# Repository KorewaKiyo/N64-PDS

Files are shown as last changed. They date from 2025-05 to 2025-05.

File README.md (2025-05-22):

# N64-PDS
## A USB-PD PSU for the Nintendo 64
This project aims to replace the bulky AC power supply of the n64 with a small, flush USB-PD supply.

The board is currently in V1 prototyping stage,
It will currently only support 15v supplies, though 5,9,15 are intended to be supported.
### Board view
animation

rendered with [kicad-render](https://github.com/linalinn/kicad-render)

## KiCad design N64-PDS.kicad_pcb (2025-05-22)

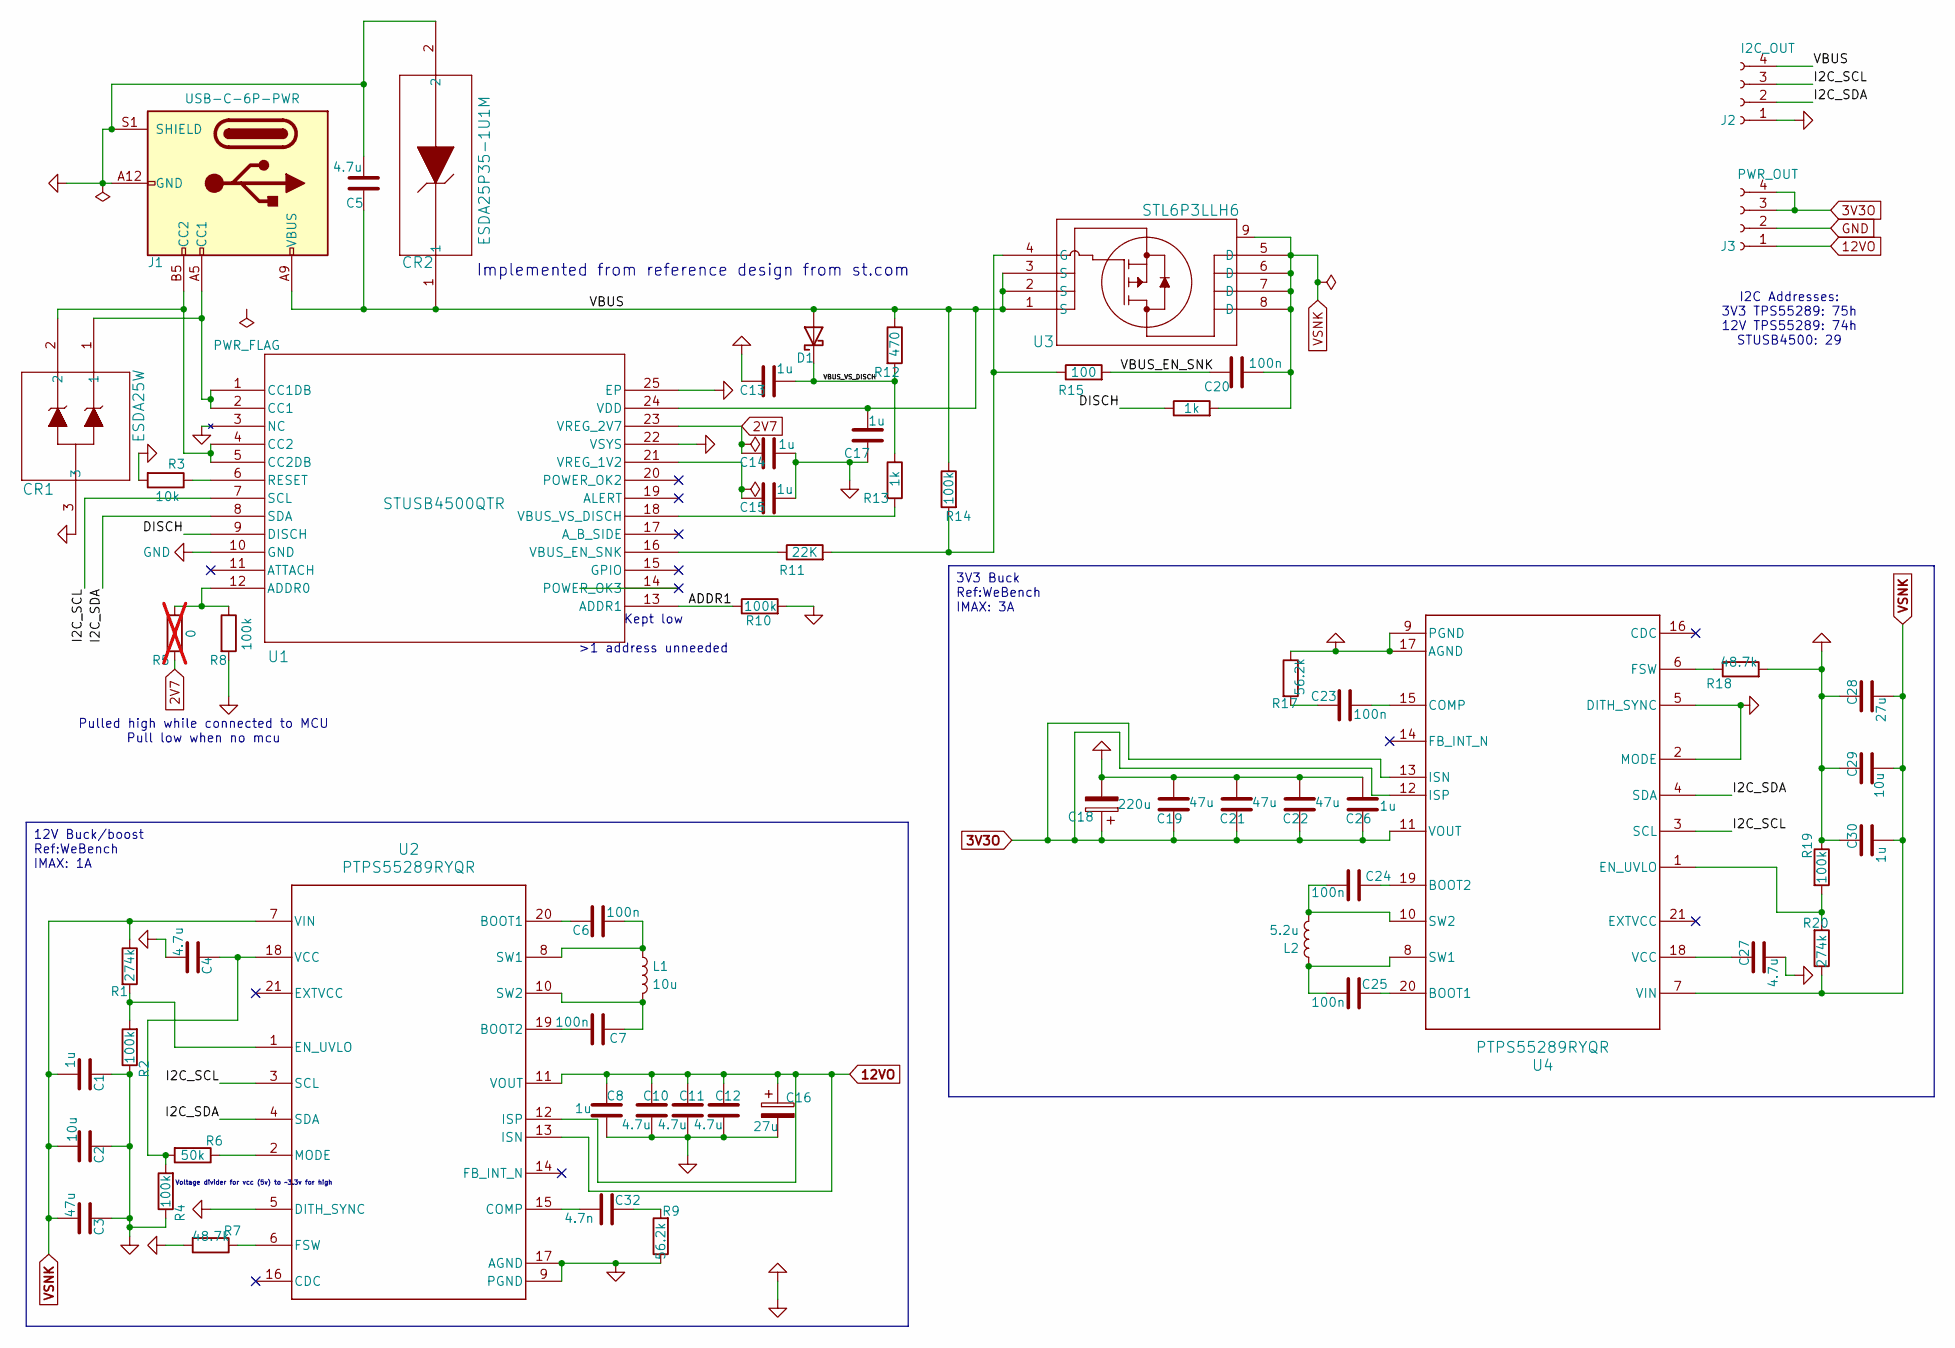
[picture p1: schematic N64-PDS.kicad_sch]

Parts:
C1, C13, C14, C15, C17, C30: 1u; C_0402_1005Metric_Pad0.74x0.62mm_HandSolder
C2, C29: 10u; C_1210_3225Metric_Pad1.33x2.70mm_HandSolder
C3: 47u; C_Elec_6.3x5.8
C4, C27: 4.7u; C_0603_1608Metric_Pad1.08x0.95mm_HandSolder
C5, C10, C11, C12: 4.7u; C_0805_2012Metric_Pad1.18x1.45mm_HandSolder
C6, C7, C24, C25: 100n; C_0603_1608Metric_Pad1.08x0.95mm_HandSolder
C8, C26: 1u; C_0603_1608Metric_Pad1.08x0.95mm_HandSolder
C16: 27u; CP_Elec_5x5.9
C18: 220u; CP_Elec_6.3x5.9
C19, C21, C22: 47u; C_0805_2012Metric_Pad1.18x1.45mm_HandSolder
C20: 100n; C_0504_1310Metric_Pad0.83x1.28mm_HandSolder
C23: 100n; C_0402_1005Metric_Pad0.74x0.62mm_HandSolder
C28: 27u; C_Elec_5x5.8
C32: 4.7n; C_0402_1005Metric_Pad0.74x0.62mm_HandSolder
CR1: ESDA25W; SOT323-3L_STM-M
CR2: ESDA25P35-1U1M; QFN1610_STM-M
D1: D_0402_1005Metric_Pad0.77x0.64mm_HandSolder
J1: USB-C-6P-PWR; USB_C_Receptacle_GCT_USB4125-xx-x-0190_6P_TopMnt_Horizontal
J2: I2C_OUT; Molex_PicoBlade_53047-0410_1x04_P1.25mm_Vertical
J3: PWR_OUT; JST_NV_B04P-NV_1x04_P5.00mm_Vertical
L1: 10u; DR1040-5R2-R
L2: 5.2u; L_Coilcraft_XAL6060-XXX
R1, R20: 274k; R_0402_1005Metric_Pad0.72x0.64mm_HandSolder
R2, R4, R8, R10, R14, R19: 100k; R_0402_1005Metric_Pad0.72x0.64mm_HandSolder
R3: 10k; R_0402_1005Metric_Pad0.72x0.64mm_HandSolder
R5: 0; R_0402_1005Metric_Pad0.72x0.64mm_HandSolder; not fitted
R6: 50k; R_0402_1005Metric_Pad0.72x0.64mm_HandSolder
R7, R18: 48.7k; R_0402_1005Metric_Pad0.72x0.64mm_HandSolder
R9, R17: 56.2k; R_0402_1005Metric_Pad0.72x0.64mm_HandSolder
R11: 22K; R_0402_1005Metric_Pad0.72x0.64mm_HandSolder
R12: 470; R_0402_1005Metric_Pad0.72x0.64mm_HandSolder
R13, R16: 1k; R_0402_1005Metric_Pad0.72x0.64mm_HandSolder
R15: 100; R_0402_1005Metric_Pad0.72x0.64mm_HandSolder
U1: STUSB4500QTR; QFN24EP_4X4_STM-M
U2, U4: PTPS55289RYQR; RYQ0021A-MFG
U3: STL6P3LLH6; POWERFLAT_3P3X3P3_STM

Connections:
2V7: C14.1, R5.2, U1.23 (VREG_2V7)
3V3O: C18.1, C19.2, C21.2, C22.2, C26.2, J3.3, J3.4, U4.11 (VOUT), U4.12 (ISP), U4.13 (ISN)
12VO: C8.2, C10.2, C11.2, C12.2, C16.1, J3.1, U2.11 (VOUT), U2.12 (ISP), U2.13 (ISN)
/ADDR1: R10.1, U1.13 (ADDR1)
/DISCH: R16.1, U1.9 (DISCH)
/I2C_SCL: J2.3, U1.7 (SCL), U2.3 (SCL), U4.3 (SCL)
/I2C_SDA: J2.2, U1.8 (SDA), U2.4 (SDA), U4.4 (SDA)
/VBUS: C5.1, C17.1, CR2.1, D1.2 (A), J1.A9 (VBUS), J1.B9 (VBUS), J2.4, R12.1, R14.1, U1.24 (VDD), U3.1 (S), U3.2 (S), U3.3 (S)
/VBUS_EN_SNK: C20.1, R15.2
/VBUS_VS_DISCH: C13.2, D1.1 (K), R12.2, R13.1
GND: C1.2, C2.2, C3.2, C4.1, C5.2, C8.1, C10.1, C11.1, C12.1, C13.1, C14.2, C15.2, C16.2, C17.2, C18.2, C19.1, C21.1, C22.1, C26.1, C27.1, C28.2, C29.2, C30.2, CR1.3, CR2.2, J1.A12 (GND), J1.B12 (GND), J1.S1 (SHIELD), J2.1, J3.2, R2.1, R3.2, R4.1, R7.2, R8.2, R9.1, R10.2, R17.1, R18.2, R19.1, U1.3 (NC), U1.10 (GND), U1.22 (VSYS), U1.25 (EP), U2.5 (DITH_SYNC), U2.9 (PGND), U2.17 (AGND), U4.2 (MODE), U4.5 (DITH_SYNC), U4.9 (PGND), U4.17 (AGND)
unnamed: C23.1, R17.2
unnamed: C32.1, R9.2
unnamed: CR1.1, J1.A5 (CC1), U1.1 (CC1DB), U1.2 (CC1)
unnamed: CR1.2, J1.B5 (CC2), U1.4 (CC2), U1.5 (CC2DB)
unnamed: R5.1, R8.1, U1.12 (ADDR0)
unnamed: R3.1, U1.6 (RESET)
unnamed: R11.1, U1.16 (VBUS_EN_SNK)
unnamed: R13.2, U1.18 (VBUS_VS_DISCH)
unnamed: C15.1, U1.21 (VREG_1V2)
unnamed: C6.1, U2.20 (BOOT1)
unnamed: C7.2, U2.19 (BOOT2)
unnamed: C32.2, U2.15 (COMP)
unnamed: R1.2, R2.2, U2.1 (EN_UVLO)
unnamed: R7.1, U2.6 (FSW)
unnamed: R6.1, U2.2 (MODE)
unnamed: C6.2, L1.1, U2.8 (SW1)
unnamed: C7.1, L1.2, U2.10 (SW2)
unnamed: C4.2, R4.2, R6.2, U2.18 (VCC)
unnamed: R11.2, R14.2, R15.1, U3.4 (G)
unnamed: C25.1, U4.20 (BOOT1)
unnamed: C24.1, U4.19 (BOOT2)
unnamed: C23.2, U4.15 (COMP)
unnamed: R19.2, R20.2, U4.1 (EN_UVLO)
unnamed: R18.1, U4.6 (FSW)
unnamed: C25.2, L2.1, U4.8 (SW1)
unnamed: C24.2, L2.2, U4.10 (SW2)
unnamed: C27.2, U4.18 (VCC)
VSNK: C1.1, C2.1, C3.1, C20.2, C28.1, C29.1, C30.1, R1.1, R16.2, R20.1, U2.7 (VIN), U3.5 (D), U3.6 (D), U3.7 (D), U3.8 (D), U3.9, U4.7 (VIN)

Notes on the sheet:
Kept low >1 address unneeded
Voltage divider for vcc (5v) to ~3.3v for high
Implemented from reference design from st.com
I2C Addresses: 3V3 TPS55289: 75h 12V TPS55289: 74h STUSB4500: 29
Pulled high while connected to MCU Pull low when no mcu
3V3 Buck Ref:WeBench IMAX: 3A
12V Buck/boost Ref:WeBench IMAX: 1A

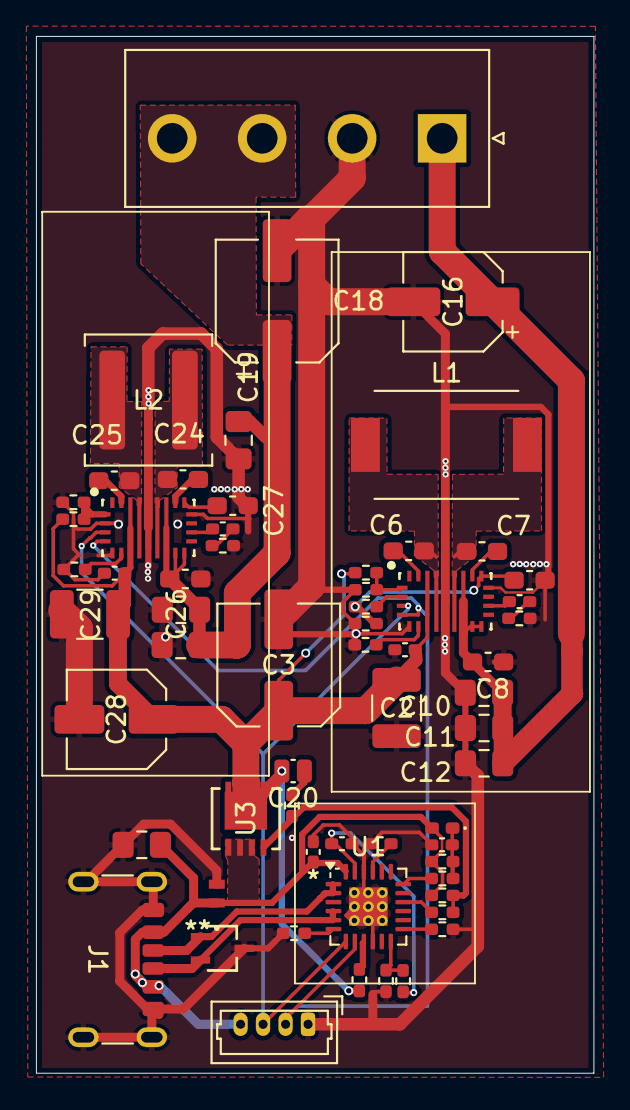
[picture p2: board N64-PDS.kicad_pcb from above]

Board: 2 copper layers, 31.0 x 57.6 mm, 69 parts (0 on the bottom side), 39 nets.

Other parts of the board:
kibuzzard-682FAEAC: G***; kibuzzard-682FAEAC
kibuzzard-682FAEBC: G***; kibuzzard-682FAEBC
kibuzzard-682FAEC4: G***; kibuzzard-682FAEC4
kibuzzard-682FAECA: G***; kibuzzard-682FAECA
kibuzzard-682FAF0F: G***; kibuzzard-682FAF0F
kibuzzard-682FAF07: G***; kibuzzard-682FAF07
kibuzzard-682FAF25: G***; kibuzzard-682FAF25

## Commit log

2024-10-04 V1.0
    The initial finished V1 board,
    15V PD in, 3.3v and 12v out
    [N64-PDS.kicad_pcb, N64-PDS.kicad_sch]
2024-10-04 Update annotations
    Whoopsy!!
    I updated all the annotations geographically on the pcb and didnt update the schematic from the pcb, all fixed :)
    [N64-PDS.kicad_pcb, N64-PDS.kicad_sch]
2024-10-10 Update PCB
    slight reshuffle of the PCB in the aim of reducing noise from smps
    [N64-PDS.kicad_pcb, N64-PDS.kicad_sch]
2024-10-10 Re-route
    Re-route to improve design, further updates to come
    [N64-PDS.kicad_pcb, N64-PDS.kicad_sch]
2024-10-11 4Layer
    4 layer board, destroy 12v rail to make space for new 12v rail.
    [N64-PDS.kicad_pcb]
2024-10-11 Component switch
    Switch buck/boost converter components, Complete schematic
    [N64-PDS.kicad_pcb, N64-PDS.kicad_sch]
2024-10-17 Add footprint, assign all component footprints.
    [N64-PDS.kicad_sch]
2024-10-25 Update footprints
2024-10-25 Update mosfet footprint & symbol
2024-10-25 Update board
    [N64-PDS.kicad_pcb, N64-PDS.kicad_sch]
2024-11-06 Finish board layout and routing
    Finished board layout and routing, added a hatched ground plane for looks (and some emi)
    [N64-PDS.kicad_pcb, N64-PDS.kicad_sch]
2024-11-11 Finalise PCB
    Finalise PCB, sent off to JLC for PCB fabrication.
    [N64-PDS.kicad_pcb]
2025-05-20 Kicad 9
    [N64-PDS.kicad_pcb, N64-PDS.kicad_sch]
2025-05-22 Oops all redesigns
    I did it again, this time smaller, better laid out, and all around maybe gooderer
    [N64-PDS.kicad_pcb, N64-PDS.kicad_sch]
2025-05-28 Groundplane tidy up
    Tidy up the backside a little to make the ground plane less segmented.
